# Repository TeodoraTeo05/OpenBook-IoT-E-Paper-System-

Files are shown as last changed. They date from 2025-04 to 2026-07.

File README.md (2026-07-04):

# OpenBook

## General Description

OpenBook is a portable e-book reader device based on the ESP32-C6. The device features an e-paper screen, control buttons, an environmental sensor, a real-time clock, and the ability to be powered by a Li-Po battery, designed as an energy-efficient and scalable system.
---

#### 1 Block Diagram

Block Diagram

---
## 2 BOM (Bill of Materials)

| Part | Device | Datasheet |
|---|---|---|
| CHG_LED | ADAFRUIT_LEDCHIP-LED0603 | [ADAFRUIT_LEDCHIP-LED0603](https://www.snapeda.com/parts/KP-1608SURCK/Kingbright/view-part/?ref=search&t=LED%200603) |
| SJ1 | SJ | [SJ](https://grabcad.com/library/solder-jumpers-1) |
| EPD_C5 | EAGLE-LTSPICE_CC0402 | [EAGLE-LTSPICE_CC0402](https://www.snapeda.com/parts/PGB1010603MR/Littelfuse/view-part/?ref=eda) |
| R3 | ESP32_WROVER_EAGLE-LTSPICE_RR0402 | (https://componentsearchengine.com/part-view/R0402%201%25%20100%20K%20(RC0402FR-07100KL)/YAGEO) |
| R1_PWRUSB | ESP32_WROVER_EAGLE-LTSPICE_RR0402 | (https://componentsearchengine.com/part-view/R0402%201%25%20100%20K%20(RC0402FR-07100KL) |
| C4_USB | EAGLE-LTSPICE_CC0402 | [EAGLE-LTSPICE_CC0402](https://componentsearchengine.com/part-view/CC0402MRX5R5BB106/YAGEO) |
| C1, C2, C6, C8, C9, C10, C_DELAY | ESP32_WROVER_EAGLE-LTSPICE_CC0402 | [ESP32_WROVER_EAGLE-LTSPICE_CC0402](https://componentsearchengine.com/part-view/CC0402MRX5R5BB106/YAGEO) |
| C3 | RCL_CPOL-EUCT3528 | [RCL_CPOL-EUCT3528](https://componentsearchengine.com/part-view/CC0402MRX5R5BB106/YAGEO) |
| R1, R1_PINH, R1_PINH1, R2_PINH, R2_PINH1, R4, R5, R6, R7, R8, R9, R10, R_BOOT, R_CHANGE, R_CL1, R_RESET | ESP32_WROVER_EAGLE-LTSPICE_RR0402 | [ESP32_WROVER_EAGLE-LTSPICE_RR0402](https://componentsearchengine.com/part-view/R0402%201%25%20100%20K%20(RC0402FR-07100KL)/YAGEO) |
| C7 | ESP32_WROVER_EAGLE-LTSPICE_CC0402 | [ESP32_WROVER_EAGLE-LTSPICE_CC0402](https://componentsearchengine.com/part-view/CC0402MRX5R5BB106/YAGEO) |
| J4 | 112A-TAAR-R03_ATTEND | [112A-TAAR-R03_ATTEND](https://store.comet.srl.ro/Catalogue/Product/43497/) |
| R_CAPACITOR | ESP32_WROVER_EAGLE-LTSPICE_RR0402 | [ESP32_WROVER_EAGLE-LTSPICE_RR0402](https://componentsearchengine.com/part-view/R0402%201%25%20100%20K%20(RC0402FR-07100KL)/YAGEO) |
| C5 | ESP32_WROVER_EAGLE-LTSPICE_CC0402 | [ESP32_WROVER_EAGLE-LTSPICE_CC0402](https://componentsearchengine.com/part-view/CC0402MRX5R5BB106/YAGEO) |
| EPD_C6, EPD_C7, EPD_C8, EPD_C9, EPD_C10, EPD_C11, EPD_C12 | EAGLE-LTSPICE_CC0402 | [EAGLE-LTSPICE_CC0402](https://componentsearchengine.com/part-view/CC0402MRX5R5BB106/YAGEO) |
| EPD_C1, EPD_C2 | ESP32_WROVER_EAGLE-LTSPICE_CC0402 | [ESP32_WROVER_EAGLE-LTSPICE_CC0402](https://componentsearchengine.com/part-view/CC0402MRX5R5BB106/YAGEO) |
| R2 | ESP32_WROVER_EAGLE-LTSPICE_RR0402 | [ESP32_WROVER_EAGLE-LTSPICE_RR0402](https://componentsearchengine.com/part-view/R0402%201%25%20100%20K%20(RC0402FR-07100KL)/YAGEO) |
| R1_BAT | ESP32_WROVER_EAGLE-LTSPICE_RR0402 | [ESP32_WROVER_EAGLE-LTSPICE_RR0402](https://componentsearchengine.com/part-view/R0402%201%25%20100%20K%20(RC0402FR-07100KL)/YAGEO) |
| Q1, Q2 | ESP32_WROVER_SPARKFUN-DISCRETESEMI_MOSFET_PCH-DMG2305UX-7 | [ESP32_WROVER_SPARKFUN-DISCRETESEMI_MOSFET_PCH-DMG2305UX-7](https://componentsearchengine.com/part-view/DMG2305UX-7/Diodes%20Incorporated) |
| R2_BAT | ESP32_WROVER_EAGLE-LTSPICE_RR0402 | [ESP32_WROVER_EAGLE-LTSPICE_RR0402](https://componentsearchengine.com/part-view/R0402%201%25%20100%20K%20(RC0402FR-07100KL)/YAGEO) |
| C5_USB | EAGLE-LTSPICE_CC0402 | [EAGLE-LTSPICE_CC0402](https://componentsearchengine.com/part-view/CC0402MRX5R5BB106/YAGEO) |
| C1_BAT, C1_BAT1, C1_BAT2, C2_BAT | ESP32_WROVER_EAGLE-LTSPICE_CC0402 | [ESP32_WROVER_EAGLE-LTSPICE_CC0402](https://componentsearchengine.com/part-view/CC0402MRX5R5BB106/YAGEO) |
| C4 | ESP32_WROVER_EAGLE-LTSPICE_CC0402 | [ESP32_WROVER_EAGLE-LTSPICE_CC0402](https://componentsearchengine.com/part-view/CC0402MRX5R5BB106/YAGEO) |
| R2-USB, R2-USB1 | ESP32_WROVER_EAGLE-LTSPICE_RR0402 | [ESP32_WROVER_EAGLE-LTSPICE_RR0402](https://componentsearchengine.com/part-view/R0402%201%25%20100%20K%20(RC0402FR-07100KL)/YAGEO) |
| L1 | 744043680IND_4828-WE-TPC_WRE | [744043680IND_4828-WE-TPC_WRE](https://eu.mouser.com/ProductDetail/Wurth-Elektronik/744043680?qs=PGXP4M47uW6VkZq%252BkzjrHA%3D%3D) |
| IC1 | BD5229G-TR | [BD5229G-TR](https://componentsearchengine.com/part-view/BD5229G-TR/ROHM%20Semiconductor) |
| SENSOR2 | ESP32_WROVER_BME680_BME680 | [ESP32_WROVER_BME680_BME680](https://www.snapeda.com/parts/BME680/Bosch/view-part/?welcome=home) |
| BUTTON_CUSYOMV1 | BUTTON_CUSYOMV1 | [BUTTON_CUSYOMV1](https://industry.panasonic.com/global/en/products/control/switch/light-touch/number/evqpuj02k) |
| C10_SUPERCAP | CPH3225A | [CPH3225A](https://www.snapeda.com/parts/CPH3225A/Seiko+Instruments/view-part/?ref=snap) |
| U3 | DS3231SN# | [DS3231SN#](https://www.snapeda.com/parts/DS3231SN%23/Analog+Devices/view-part/?ref=snap) |
| U2 | ESP32-C6-WROOM-1-N8 | [ESP32-C6-WROOM-1-N8](https://www.snapeda.com/parts/ESP32-C6-WROOM-1-N8/Espressif+Systems/view-part/?ref=eda) |
| PFMF.050.1 | ESP32C6_VARISTORCN1812 | [ESP32C6_VARISTORCN1812](https://www.mouser.co.uk/ProductDetail/EPCOS-TDK/B72520T0350K062?qs=dEfas%2FXlABIszF52uu7vrg%3D%3D) |
| D2, D7 | ESP32_WROVER_AVX---SD0805S020S1R0_AVX_SD0805S020S1R0_0_0AVX_SD0805S020S1R0_0_0 | [ESP32_WROVER_AVX---SD0805S020S1R0_AVX_SD0805S020S1R0_0_0AVX_SD0805S020S1R0_0_0](https://eu.mouser.com/ProductDetail/KYOCERA-AVX/SD0805S020S1R0?qs=jCA%252BPfw4LHbpkAoSnwrdjw%3D%3D) |
| U5 | ESP32_WROVER_SPARKFUN-IC-POWER_MCP73831 | [ESP32-C6-WROOM-1-N8](https://componentsearchengine.com/part-view/MCP73831T-2ATI%2FOT/Microchip) |
| J1 | FH34SRJ-24S-0.5SH_99_ | [FH34SRJ-24S-0.5SH_99_](https://componentsearchengine.com/part-view/XC6220A331MR-G/Torex) |
| U4 | MAX17048G+T10 | [MAX17048G+T10](https://www.snapeda.com/parts/MAX17048G+T10/Analog+Devices/view-part/?ref=snap) |
| D3, D4, D5 | MBR0530 | [MBR0530](https://www.snapeda.com/parts/MBR0530/Onsemi/view-part/?ref=snap) |
| D6, D8, D9, D10, D11, D12 | PGB1010603MR | [PGB1010603MR](https://www.snapeda.com/parts/PGB1010603MR/Littelfuse/view-part/?ref=snap) |
| J3 | QWIIC_CONNECTORJS-1MM | [QWIIC_CONNECTORJS-1MM](https://www.snapeda.com/parts/PRT-14417/SparkFun%20Electronics/view-part/?ref=search&t=qwiic) |
| J2 | SAMACSYS_PARTS_USB4110-GF-A | (https://componentsearchengine.com/part-view/USB4110-GF-A/GCT%20(GLOBAL%20CONNECTOR%20TECHNOLOGY) |
| Q3 | SI1308EDL-T1-GE3 | [SI1308EDL-T1-GE3](https://componentsearchengine.com/part-view/SI1308EDL-T1-GE3/Vishay) |
| TP1, TP2, TP3, TP4, TP5, TP6, TP7, TP8, TP9, TP10, TP11, TP12, TP13, TP14, TP15, TP16, TP17 | TPTP20R | [made by me] |
| D1 | USBLC6-2SC6Y | [USBLC6-2SC6Y](https://www.snapeda.com/parts/USBLC6-2SC6Y/STMicroelectronics/view-part/?ref=snap) |
| U1 | W25Q512JVEIQ | [W25Q512JVEIQ](https://www.snapeda.com/parts/W25Q512JVEIQ/Winbond+Electronics/view-part/?ref=snap) |
| IC4 | XC6220A331MR-G | [XC6220A331MR-G](https://componentsearchengine.com/part-view/XC6220A331MR-G/Torex) |

## 3. Hardware Functionality

The OpenBook project is an e-paper reader, powered by a LiPo battery and built around the ESP32-C3-WROOM microcontroller. 
The device collects environmental data (temperature, humidity, CO2, particles), saves them to a microSD card, and can display them on the e-paper screen.

### ESP32-C3-WROOM
- Main module with Wi-Fi/BLE connectivity, capable of communicating via SPI, I2C, and UART.
- Supply voltage: 3.3V, provided by an LDO.

### Power System
- **USB-C** is used for charging and USB communication.
- **MCP73832** manages the LiPo battery charging.
- **3.3V LDO** powers the ESP32 and the rest of the components at 3.3V.
- **5V DC/DC** generates 5V for sensors that require a higher voltage (PM and CO2).

### Sensors
- **BME680** - temperature, humidity, and gas sensor, communicates via I2C.
- **MH-Z19B** - CO2 sensor powered at 5V, communicates via UART.
- **PMSA003** - fine particle sensor (PM2.5), communicates via UART, 5V.

### Display
- 1.5" monochrome e-paper display with 200x200 px resolution.
- Shared SPI interface with the SD Card.

### SD Card
- Module for storing collected data or text files.
- SPI interface.

### Buttons
- 3 tactile buttons connected to GPIO for interface control (e.g., menu navigation, screen refresh).

### Estimated power consumption calculations (average values)

| Module | Voltage | Current (mA) | Estimated Consumption |
|---|---|---|---|
| ESP32-C3 | 3.3V | 80-150 | 0.3-0.5W |
| E-Ink Display | 3.3V | 10 (refresh) | 0.03W |
| BME680 | 3.3V | 2-3 | 0.01W |
| MH-Z19B | 5V | 40-50 | 0.25W |
| PMSA003 | 5V | 60-100 | 0.5W |
| SD Card | 3.3V | 10 | 0.03W |
| MCP73832 (charger) | 5V | 1000 (max) | only when charging |

**Deep sleep mode:** Total consumption under 1 mA. Ideal for a portable device.

## 4. ESP32-C3 Pinout

| ESP32-C3 Pin | Component | Reason / Signal |
|---|---|---|
| GPIO1 (I2C SDA) | BME680 | I2C Communication |
| GPIO2 (I2C SCL) | BME680 | I2C Communication |
| GPIO3 (UART RX) | PMSA003 | UART RX PM sensor |
| GPIO4 (SPI CS SD)| SD Card | SD Card Chip Select |
| GPIO5 | E-Ink DC | Data/Command E-Ink |
| GPIO6 (SPI CLK) | E-Ink & SD | SPI Clock |
| GPIO7 (SPI MOSI) | E-Ink & SD | SPI Data |
| GPIO8 (GPIO) | Button 1 | Menu control / page flip |
| GPIO9 (GPIO) | Button 2 | Menu control / page flip |
| GPIO10 (SPI CS) | E-Ink Display | e-paper Chip Select |
| GPIO11 (SPI CS) | External Flash (optional)| N/A |
| GPIO12 (USB D-) | USB | USB Communication |
| GPIO13 (USB D+) | USB | USB Communication |
| GPIO18 | MH-Z19B (UART TX) | UART for CO2 sensor |
| GPIO19 | Button 3 | Navigation / confirm |

## 5. Other relevant aspects

- The PCB design follows the recommendations for power traces (min 0.3mm) and signal traces (min 0.15mm).
- The ESP32-C3 antenna is placed towards the outside of the board, and the area underneath it is cut out.
- Decoupling capacitors are placed close to the VCC of the components.
- Solid ground plane on both layers and active via stitching.
- All passive components are SMD 0402.
- The layout is designed in Fusion360, aligned with the physical case dimensions.
- Rendered images of the device and case can be found in the `Images/` folder of this repository.

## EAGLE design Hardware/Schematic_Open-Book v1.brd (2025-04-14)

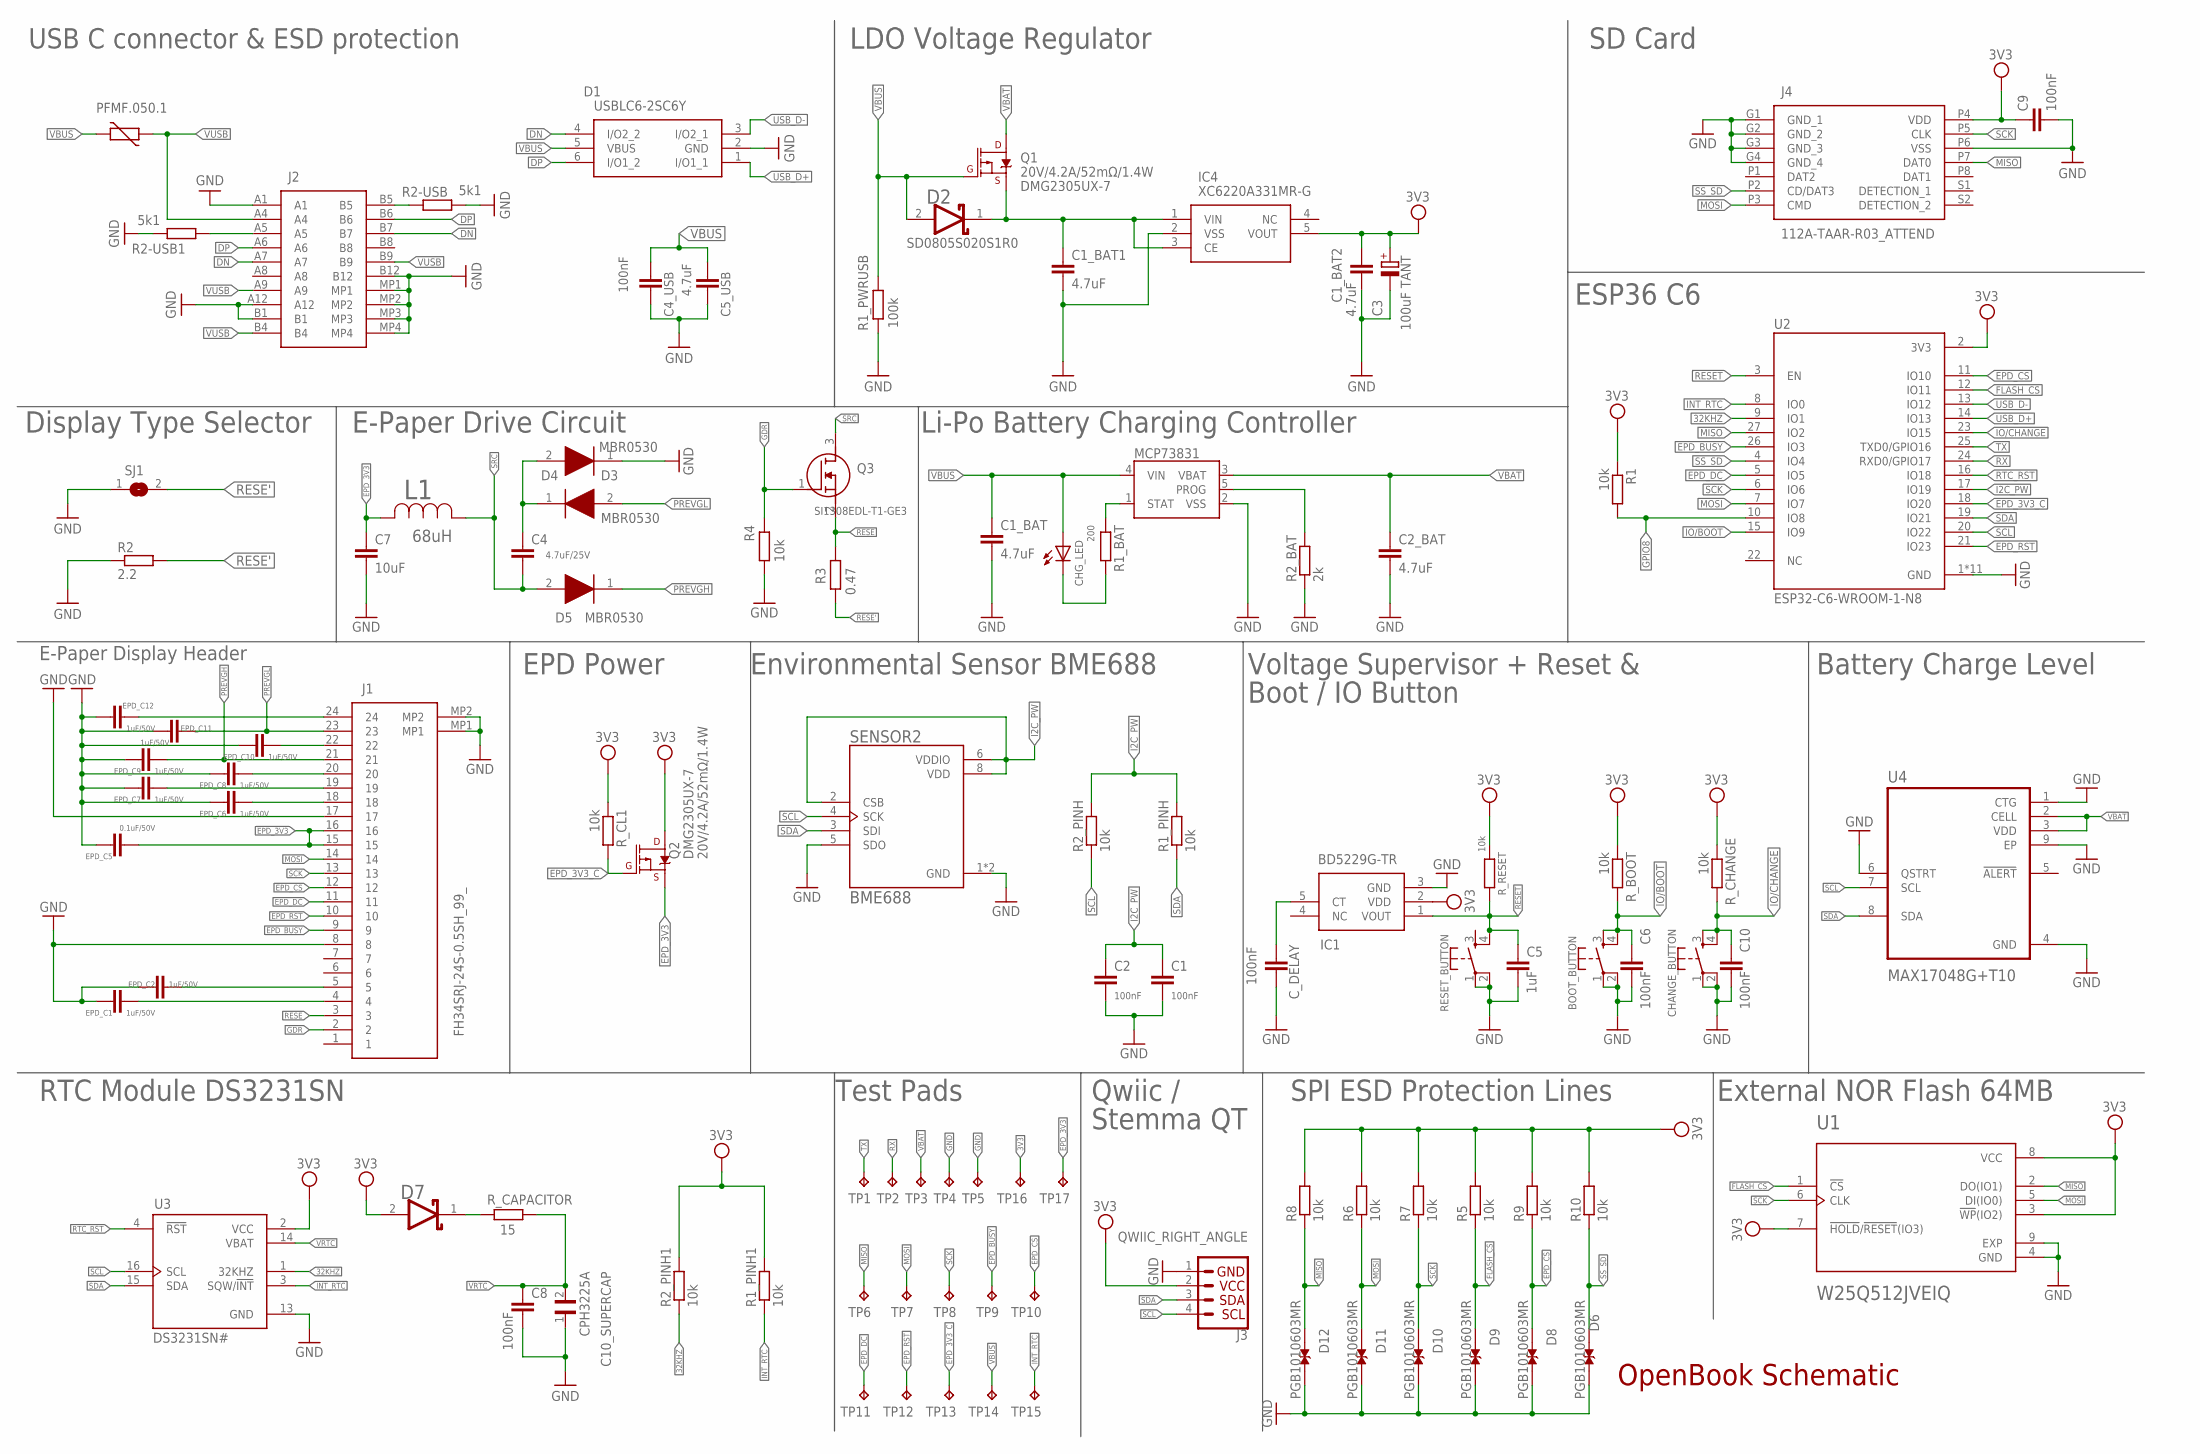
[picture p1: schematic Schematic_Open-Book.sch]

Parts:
BOOT_BUTTON: BOOT_BUTTON; MYBUTTON
C1, C2, C6, C8, C9, C10: 100nF; ESP32_WROVER_EAGLE-LTSPICE_C0402
C1_BAT, C1_BAT1, C1_BAT2, C2_BAT: 4.7uF; ESP32_WROVER_EAGLE-LTSPICE_C0402
C3: 100uF TANT; RCL_CT3528
C4: 4.7uF/25V; ESP32_WROVER_EAGLE-LTSPICE_C0402
C4_USB: 100nF; EAGLE-LTSPICE_C0402
C5: 1uF; ESP32_WROVER_EAGLE-LTSPICE_C0402
C5_USB: 4.7uF; EAGLE-LTSPICE_C0402
C7: 10uF; ESP32_WROVER_EAGLE-LTSPICE_C0402
C10_SUPERCAP: CPH3225A; CAPCP3225X100N
CHANGE_BUTTON: CHANGE_BUTTON; MYBUTTON
CHG_LED: ADAFRUIT_LEDCHIP-LED0603; ADAFRUIT_CHIP-LED0603
C_DELAY: 100nF; ESP32_WROVER_EAGLE-LTSPICE_C0402
D1: USBLC6-2SC6Y; SOT95P280X145-6N
D2, D7: ESP32_WROVER_AVX---SD0805S020S1R0_AVX_SD0805S020S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; ESP32_WROVER_AVX---SD0805S020S1R0_AVX_SD0805S020S1R0_0
D3, D4, D5: MBR0530; SOD3716X135N
D6, D8, D9, D10, D11, D12: PGB1010603MR; DIOC1608X36N
EPD_C1, EPD_C2: 1uF/50V; ESP32_WROVER_EAGLE-LTSPICE_C0402
EPD_C5: 0.1uF/50V; EAGLE-LTSPICE_C0402
EPD_C6, EPD_C7, EPD_C8, EPD_C9, EPD_C10, EPD_C11, EPD_C12: 1uF/50V; EAGLE-LTSPICE_C0402
IC1: BD5229G-TR; SOT95P280X125-5N
IC4: XC6220A331MR-G; SOT95P280X120-5N
J1: FH34SRJ-24S-0.5SH_99_; FH34SRJ24S05SH99
J2: SAMACSYS_PARTS_USB4110-GF-A; SAMACSYS_PARTS_USB4110GFA
J3: QWIIC_RIGHT_ANGLE; JST04_1MM_RA
J4: 112A-TAAR-R03_ATTEND; 112ATAARR03ATTEND
L1: 68uH; IND_4828-WE-TPC_WRE
MCP73831: ESP32_WROVER_SPARKFUN-IC-POWER_MCP73831; ESP32_WROVER_SPARKFUN-IC-POWER_SOT23-5
PFMF.050.1: ESP32C6_VARISTORCN1812; ESP32C6_VARISTOR_CT/CN1812
Q1, Q2: 20V/4.2A/52mΩ/1.4W; ESP32_WROVER_SPARKFUN-DISCRETESEMI_SOT23-3
Q3: SI1308EDL-T1-GE3; SOT65P210X110-3N
R1, R1_PINH, R1_PINH1, R2_PINH, R2_PINH1, R4, R5, R6, R7, R8, R9, R10: 10k; ESP32_WROVER_EAGLE-LTSPICE_R0402
R1_BAT: 200; ESP32_WROVER_EAGLE-LTSPICE_R0402
R1_PWRUSB: 100k; ESP32_WROVER_EAGLE-LTSPICE_R0402
R2: 2.2; ESP32_WROVER_EAGLE-LTSPICE_R0402
R2-USB, R2-USB1: 5k1; ESP32_WROVER_EAGLE-LTSPICE_R0402
R2_BAT: 2k; ESP32_WROVER_EAGLE-LTSPICE_R0402
R3: 0.47; ESP32_WROVER_EAGLE-LTSPICE_R0402
RESET_BUTTON: RESET_BUTTON; MYBUTTON
R_BOOT: 10k; ESP32_WROVER_EAGLE-LTSPICE_R0402
R_CAPACITOR: 15; ESP32_WROVER_EAGLE-LTSPICE_R0402
R_CHANGE: 10k; ESP32_WROVER_EAGLE-LTSPICE_R0402
R_CL1: 10k; ESP32_WROVER_EAGLE-LTSPICE_R0402
R_RESET: 10k; ESP32_WROVER_EAGLE-LTSPICE_R0402
SENSOR2: BME688; ESP32_WROVER_BME680_PSON80P300X300X100-8N
SJ1: SJ
TP1, TP2, TP3, TP4, TP5, TP6, TP7, TP8, TP9, TP10, TP11, TP12, TP13, TP14, TP15, TP16, TP17: TPTP20R; TP20R
U1: W25Q512JVEIQ; SON127P600X800X80-9N
U2: ESP32-C6-WROOM-1-N8; XCVR_ESP32-C6-WROOM-1-N8
U3: DS3231SN#; SOIC127P1032X265-16N
U4: MAX17048G+T10; SON50P200X200X80-9N

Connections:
3V3: C1_BAT2.1, C3.+, C9.1, D7.2 (ANODE), IC1.2 (VDD), IC4.5 (VOUT), J3.2, J4.P4 (VDD), Q2.3 (D), R1.1, R1_PINH1.2, R2_PINH1.2, R5.2, R6.2, R7.2, R8.2, R9.2, R10.2, R_BOOT.1, R_CHANGE.1, R_CL1.1, R_RESET.1, TP16.TP, U1.3 (!WP!(IO2)), U1.7 (!HOLD!/!RESET!(IO3)), U1.8 (VCC), U2.2 (3V3), U3.2 (VCC)
32KHZ: R2_PINH1.1, U2.9 (IO1), U3.1 (32KHZ)
DN: D1.4 (I/O2_2), J2.A7, J2.B7
DP: D1.6 (I/O1_2), J2.A6, J2.B6
EPD_3V3: C7.1, EPD_C5.1, J1.15, J1.16, L1.2, Q2.2 (S), TP17.TP
EPD_3V3_C: Q2.1 (G), R_CL1.2, TP13.TP, U2.18 (IO20)
EPD_BUSY: J1.9, TP9.TP, U2.26 (IO3)
EPD_CS: D8.1, J1.12, R9.1, TP10.TP, U2.11 (IO10)
EPD_DC: J1.11, TP11.TP, U2.5 (IO5)
EPD_RST: J1.10, TP12.TP, U2.21 (IO23)
FLASH_CS: D9.1, R5.1, U1.1 (!CS), U2.12 (IO11)
GDR: J1.2, Q3.1 (G), R4.1
GND: BOOT_BUTTON.1, BOOT_BUTTON.2, C1.2, C1_BAT.2, C1_BAT1.2, C1_BAT2.2, C2.2, C2_BAT.2, C3.-, C4_USB.2, C5.2, C5_USB.2, C6.2, C7.2, C8.2, C9.2, C10.2, C10_SUPERCAP.1, CHANGE_BUTTON.1, CHANGE_BUTTON.2, C_DELAY.2, D1.2 (GND), D4.1 (K), D6.2, D8.2, D9.2, D10.2, D11.2, D12.2, EPD_C1.2, EPD_C2.2, EPD_C5.2, EPD_C6.2, EPD_C7.2, EPD_C8.2, EPD_C9.2, EPD_C10.2, EPD_C11.2, EPD_C12.2, IC1.3 (GND), IC4.2 (VSS), J1.8, J1.17, J1.MP1, J1.MP2, J2.A1, J2.A12, J2.B1, J2.B12, J2.MP1, J2.MP2, J2.MP3, J2.MP4, J3.1, J4.G1 (GND_1), J4.G2 (GND_2), J4.G3 (GND_3), J4.G4 (GND_4), J4.P6 (VSS), MCP73831.2 (VSS), R1_PWRUSB.2, R2.1, R2-USB.2, R2-USB1.1, R2_BAT.1, R4.2, RESET_BUTTON.1, RESET_BUTTON.2, SENSOR2.1 (GND), SENSOR2.5 (SDO), SENSOR2.7 (GND), SJ1.1, TP4.TP, TP5.TP, U1.4 (GND), U1.9 (EXP), U2.1 (GND), U2.28 (GND), U2.29_1 (GND), U2.29_2 (GND), U2.29_3 (GND), U2.29_4 (GND), U2.29_5 (GND), U2.29_6 (GND), U2.29_7 (GND), U2.29_8 (GND), U2.29_9 (GND), U3.13 (GND), U4.1 (CTG), U4.4 (GND), U4.6 (QSTRT), U4.9 (EP)
GPIO8: R1.2, U2.10 (IO8)
I2C_PW: C1.1, C2.1, R1_PINH.2, R2_PINH.2, SENSOR2.2 (CSB), SENSOR2.6 (VDDIO), SENSOR2.8 (VDD), U2.17 (IO19)
INT_RTC: R1_PINH1.1, TP15.TP, U2.8 (IO0), U3.3 (SQW/!INT)
IO/BOOT: BOOT_BUTTON.3, BOOT_BUTTON.4, C6.1, R_BOOT.2, U2.15 (IO9)
IO/CHANGE: C10.1, CHANGE_BUTTON.3, CHANGE_BUTTON.4, R_CHANGE.2, U2.23 (IO15)
MISO: D12.1, J4.P7 (DAT0), R8.1, TP6.TP, U1.2 (DO(IO1)), U2.27 (IO2)
MOSI: D11.1, J1.14, J4.P3 (CMD), R6.1, TP7.TP, U1.5 (DI(IO0)), U2.7 (IO7)
unnamed: J2.B5, R2-USB.1
unnamed: J2.A5, R2-USB1.2
unnamed: C4.1, D3.1 (K), D4.2 (A)
unnamed: C1_BAT1.1, D2.1 (CATHODE), IC4.1 (VIN), IC4.3 (CE), Q1.2 (S)
unnamed: MCP73831.5 (PROG), R2_BAT.2
unnamed: CHG_LED.C, R1_BAT.2
unnamed: MCP73831.1 (STAT), R1_BAT.1
unnamed: C_DELAY.1, IC1.5 (CT)
unnamed: EPD_C2.1, J1.5
unnamed: EPD_C1.1, J1.4
unnamed: D7.1 (CATHODE), R_CAPACITOR.2
unnamed: EPD_C12.1, J1.24
unnamed: EPD_C10.1, J1.22
unnamed: EPD_C8.1, J1.20
unnamed: EPD_C7.1, J1.19
unnamed: EPD_C6.1, J1.18
PREVGH: D5.1 (K), EPD_C9.1, J1.21
PREVGL: D3.2 (A), EPD_C11.1, J1.23
RESE: J1.3, Q3.2 (S), R3.1
RESE': R2.2, R3.2, SJ1.2
RESET: C5.1, IC1.1 (VOUT), RESET_BUTTON.4, R_RESET.2, U2.3 (EN)
RTC_RST: U2.16 (IO18), U3.4 (!RST)
RX: TP2.TP, U2.24 (RXD0/GPIO17)
SCK: D10.1, J1.13, J4.P5 (CLK), R7.1, TP8.TP, U1.6 (CLK), U2.6 (IO6)
SCL: J3.4, R2_PINH.1, SENSOR2.4 (SCK), U2.20 (IO22), U3.16 (SCL), U4.7 (SCL)
SDA: J3.3, R1_PINH.1, SENSOR2.3 (SDI), U2.19 (IO21), U3.15 (SDA), U4.8 (SDA)
SRC: C4.2, D5.2 (A), L1.1, Q3.3 (D)
SS_SD: D6.1, J4.P2 (CD/DAT3), R10.1, U2.4 (IO4)
TX: TP1.TP, U2.25 (TXD0/GPIO16)
USB_D+: D1.1 (I/O1_1), U2.14 (IO13)
USB_D-: D1.3 (I/O2_1), U2.13 (IO12)
VBAT: C2_BAT.1, MCP73831.3 (VBAT), Q1.3 (D), TP3.TP, U4.2 (CELL), U4.3 (VDD)
VBUS: C1_BAT.1, C4_USB.1, C5_USB.1, CHG_LED.A, D1.5 (VBUS), D2.2 (ANODE), MCP73831.4 (VIN), PFMF.050.1.2, Q1.1 (G), R1_PWRUSB.1, TP14.TP
VRTC: C8.1, C10_SUPERCAP.2, R_CAPACITOR.1, U3.14 (VBAT)
VUSB: J2.A4, J2.A9, J2.B4, J2.B9, PFMF.050.1.1

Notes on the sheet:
USB C connector & ESD protection
LDO Voltage Regulator
SD0805S020S1R0
DMG2305UX-7
SD Card
Display Type Selector
E-Paper Drive Circuit
Li-Po Battery Charging Controller
ESP36 C6
E-Paper Display Header
EPD Power
Environmental Sensor BME688
Voltage Supervisor + Reset &
Boot / IO Button
Battery Charge Level
RTC Module DS3231SN
Test Pads
Qwiic /
Stemma QT
SPI ESD Protection Lines
External NOR Flash 64MB
OpenBook Schematic

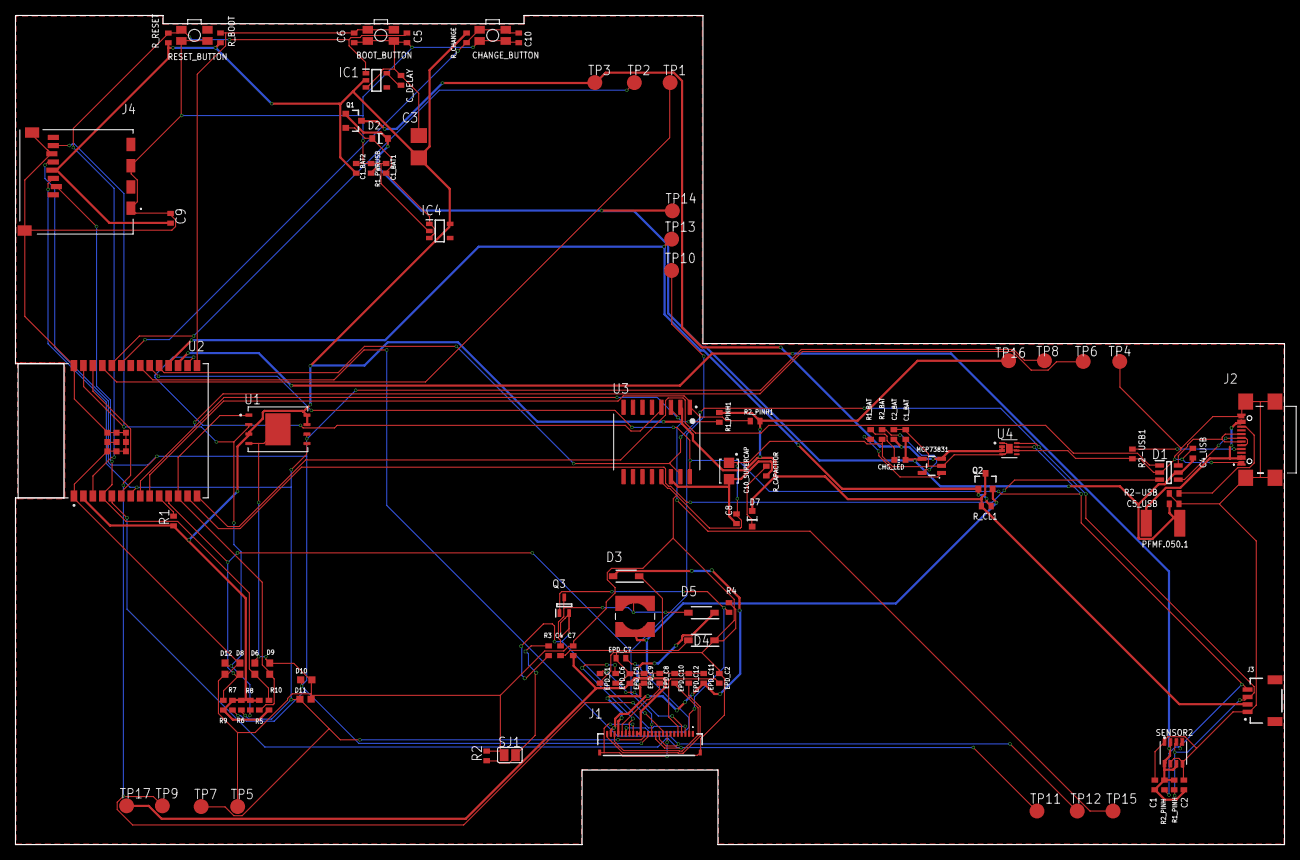
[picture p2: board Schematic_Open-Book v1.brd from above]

Board: 2 copper layers, 170.2 x 111.2 mm, 103 parts (0 on the bottom side), 55 nets.

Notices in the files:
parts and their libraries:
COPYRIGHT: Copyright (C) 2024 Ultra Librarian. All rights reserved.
